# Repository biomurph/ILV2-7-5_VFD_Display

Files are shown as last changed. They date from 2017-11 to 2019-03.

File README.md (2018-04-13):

# ILV2-7-5_VFD_Display
KiCAD circuit for a VFD Clock using the Popular ILV2-7/5 flat tube segmented nixie tube thingie

Not sure if [this link](https://www.ebay.com/itm/Lot-of-20-IVL2-7-5-IVL-VFD-DIGIT-CLOCK-DISPLAY-TUBE-GREEN-Tube-New-FREE-SHIPPING/252890205246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) still works

This work is greatly indebted to work that came before. Namely
[Callum Nunez-Vas](https://callumnunesvaz.wordpress.com/) and his [Dogbone Watch](https://callumnunesvaz.wordpress.com/portfolio/dogbonevfd/) which is also based on the [cyberpunk wristwatch](http://www.johngineer.com/blog/?p=1595) by [johngineer](http://www.johngineer.com/blog/).

I made some changes.

First, my uC is a [PIC32MX250F128B](http://www.microchip.com/wwwproducts/en/PIC32MX250F128B), which supports USB OTG, which is nice and it's also Arduino compatible via ChipKIT and Digilent's [DP32](http://chipkit.net/wiki/index.php?title=ChipKIT_DP32) which makes it nice for sharing.

The other thing that I changed is the oscillator that Callum used to drive the Cathode filament. Callum drives it with a timer on his PIC16F828. I needed more pins, so I decided to make a stand-alone relaxation oscillator built out of a [74HCG214](https://www.mouser.com/ProductDetail/Nexperia/74HC2G14GV125/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) dual Schmidtt Trigger Inverter. I set mine up as a dual oscillator clocking at ~1KHz to drive the hours/mimutes Cathodes. 

There's two pushbuttons for interfacing and an LED for control and user feedback. I'm using the same [DS3231](https://www.maximintegrated.com/en/products/digital/real-time-clocks/DS3231.html) that Callum uses, and also the [MAX6920](https://www.maximintegrated.com/en/products/power/display-power-control/MAX6920.html) for the high voltage SIPO to drive the segments.

It's pretty basic beyond that. The power supply is based on the Dogbone, but I'm using a 3V0 regulator instead of a 3V3 and I have a V-divider set up as a battery level sensor that the PIC can read. 

* Maximum input Voltage 6V
* Minimum input Voltage 3.0V
* Current with VFD DISABLED ~26mA
* Current with VFD ENABLED showing all 8s ~150mA

# Push Button Control

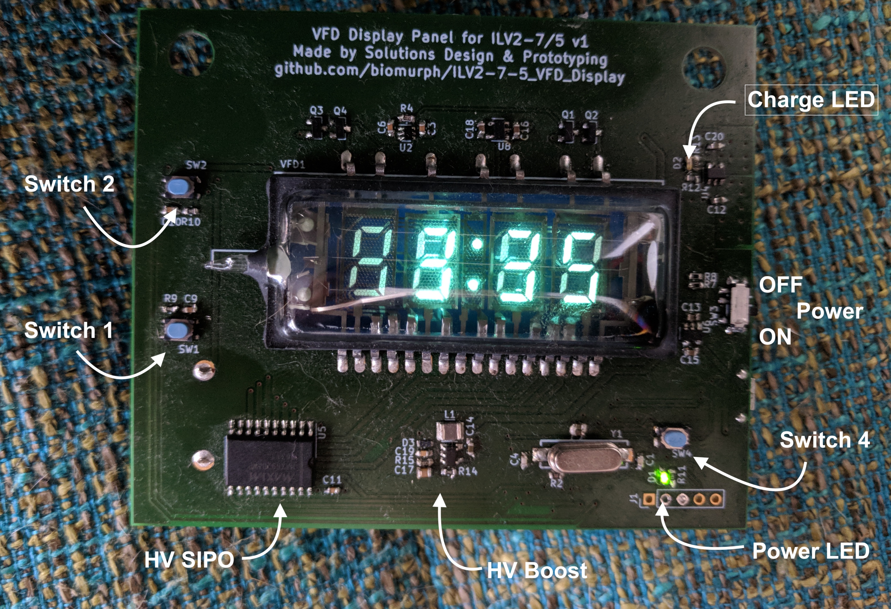
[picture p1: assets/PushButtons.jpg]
PushButtons


## Test Battery Level
Press Switch 2 once. The screen will print a lowercase `b` and then the voltage level with 0.01mV resolution. Press again to go back to time display.

## Change Time
Press Switch 1 once. Hour will blink. Press Switch 2 to increment hour.

Press Switch 1 again. Minute will blink. Press Switch 2 to increment minute.

Press Switch 1 again. Display will show option between 24 hour and 12 hour time. Press Switch 2 to toggle between 24h and 12h.

Press Switch 1 again to go back to the time display.

# Power & Charging

Switch 4 is the reset switch to the PIC. When you press it, the micro-contoller resets. It will start in 24 hour mode.

The thing runs on a high capacity LiPo battery. Plug it into a micro USB cable for charging. You can also program the PIC through the USB connection if you want to.

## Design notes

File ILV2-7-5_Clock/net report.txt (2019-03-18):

Info: Checking netlist symbol footprint “BT1:/5A063A3F:Solutions:12BH062-GR”.

Info: Checking netlist symbol footprint “C1:/5A064980:Capacitors_SMD:C_0603”.

Info: Checking netlist symbol footprint “C2:/5A0722A3:Capacitors_SMD:C_0603”.

Info: Checking netlist symbol footprint “C3:/5A072AB3:Capacitors_SMD:C_0603”.

Info: Checking netlist symbol footprint “C4:/5A0649E6:Capacitors_SMD:C_0603”.

Info: Checking netlist symbol footprint “C5:/5A07216A:Capacitors_SMD:C_0603”.

Info: Checking netlist symbol footprint “C6:/5A0621EE:Capacitors_SMD:C_0603”.

Info: Checking netlist symbol footprint “C7:/5A064D0D:Capacitors_SMD:C_0603”.

Info: Checking netlist symbol footprint “C8:/5A0717BE:Capacitors_SMD:C_0603”.

Info: Checking netlist symbol footprint “C9:/5A073D34:Capacitors_SMD:C_0603”.

Info: Checking netlist symbol footprint “C10:/5A07480A:Capacitors_SMD:C_0603”.

Info: Checking netlist symbol footprint “C11:/5A073321:Capacitors_SMD:C_0603”.

Info: Checking netlist symbol footprint “C13:/5A07925D:Capacitors_SMD:C_0603”.

Info: Checking netlist symbol footprint “Y1:/5A0644EE:Solutions:IQD_HC49_XTAL”.

Info: Checking netlist symbol footprint “C15:/5A0791BA:Capacitors_SMD:C_0603”.

Info: Checking netlist symbol footprint “C16:/5A073399:Capacitors_SMD:C_0603”.

Info: Checking netlist symbol footprint “VFD1:/5A04E81E:Solutions:IVL2-7-5”.

Info: Checking netlist symbol footprint “C17:/5A080FB1:Capacitors_THT:CP_Radial_D5.0mm_P2.00mm”.

Info: Checking netlist symbol footprint “U8:/5A04E091:TO_SOT_Packages_SMD:SOT-23-5”.

Info: Checking netlist symbol footprint “U5:/5A03AB62:Housings_SOIC:SO-20_12.8x7.5mm_Pitch1.27mm”.

Info: Checking netlist symbol footprint “C18:/5A078AB7:Capacitors_SMD:C_0603”.

Info: Checking netlist symbol footprint “C21:/5A09EB84:Capacitors_SMD:C_0603”.

Info: Checking netlist symbol footprint “D1:/5A073B5F:Capacitors_SMD:C_0603”.

Info: Checking netlist symbol footprint “D2:/5AD510A8:Capacitors_SMD:C_0603”.

Info: Changing component path “U4:/5A0386CB” to “/5AD4ED0F”.

Info: Changing component path “D2:/5A07AFE9” to “/5AD510A8”.

Info: Checking netlist symbol footprint “U4:/5AD4ED0F:TO_SOT_Packages_SMD:SOT-23”.

Info: Checking netlist symbol footprint “D3:/5A080969:Capacitors_SMD:C_0603”.

Info: Checking netlist symbol footprint “U3:/5A03A397:SMD_Packages:SOIC-28”.

Info: Checking netlist symbol footprint “J1:/5A076DD7:Pin_Headers:Pin_Header_Straight_1x05_Pitch2.54mm”.

Info: Checking netlist symbol footprint “J2:/5A04E172:Solutions:10118193_microUSB”.

Info: Checking netlist symbol footprint “U2:/5A0513A7:TO_SOT_Packages_SMD:SOT-363_SC-70-6”.

Info: Checking netlist symbol footprint “U1:/5A03A791:SMD_Packages:SOIC-8-N”.

Info: Checking netlist symbol footprint “SW4:/5A08B7A0:Solutions:PTS810”.

Info: Checking netlist symbol footprint “SW3:/5A073A0A:Solutions:C&K_OS102011MS2QN1”.

Info: Checking netlist symbol footprint “SW2:/5A073A78:Solutions:PTS810”.

Info: Checking netlist symbol footprint “SW1:/5A073B03:Solutions:PTS810”.

Info: Checking netlist symbol footprint “R11:/5A073E79:Capacitors_SMD:C_0603”.

Info: Checking netlist symbol footprint “J3:/5AD51382:Connectors:Barrel_Jack_CUI_PJ-102AH”.

Info: Checking netlist symbol footprint “R10:/5A073CB0:Capacitors_SMD:C_0603”.

Info: Checking netlist symbol footprint “Q1:/5A05E086:TO_SOT_Packages_SMD:SOT-23”.

Info: Checking netlist symbol footprint “Q2:/5A0385D3:TO_SOT_Packages_SMD:SOT-23”.

Info: Checking netlist symbol footprint “Q3:/5A062F32:TO_SOT_Packages_SMD:SOT-23”.

Info: Checking netlist symbol footprint “Q4:/5A062F2C:TO_SOT_Packages_SMD:SOT-23”.

Info: Checking netlist symbol footprint “R1:/5A064086:Capacitors_SMD:C_0603”.

Info: Checking netlist symbol footprint “R2:/5A0647AE:Capacitors_SMD:C_0603”.

Info: Checking netlist symbol footprint “R3:/5A06605B:Capacitors_SMD:C_0603”.

Info: Checking netlist symbol footprint “R4:/5A062248:Capacitors_SMD:C_0603”.

Info: Checking netlist symbol footprint “R5:/5A063C78:Capacitors_SMD:C_0603”.

Info: Checking netlist symbol footprint “R6:/5A063CCE:Capacitors_SMD:C_0603”.

Info: Checking netlist symbol footprint “R7:/5C7B733E:Capacitors_SMD:C_0603”.

Info: Checking netlist symbol footprint “R9:/5A073C03:Capacitors_SMD:C_0603”.

Info: Changing component path “R7:/5A08500A” to “/5C7B733E”.

Info: Changing component path “R8:/5A0853B7” to “/5C7B7B7C”.

Info: Checking netlist symbol footprint “R8:/5C7B7B7C:Capacitors_SMD:C_0603”.

Changing footprint “R7:/5A08500A” pad “1” net name from “/BAT_SENS” to “Net-(J2-Pad3)”.

Changing footprint “R8:/5A0853B7” value from “100K” to “22R”.

Changing footprint “R7:/5A08500A” pad “2” net name from “/V_BAT” to “/D+”.

Changing footprint “R8:/5A0853B7” pad “2” net name from “/BAT_SENS” to “/D-”.

Changing footprint “R8:/5A0853B7” pad “1” net name from “GND” to “Net-(J2-Pad2)”.

Changing footprint “R7:/5A08500A” value from “100K” to “22R”.

Adding new symbol “J3:/5AD51382” footprint “Connectors:Barrel_Jack_CUI_PJ-102AH”.

Clearing component “J2:/5A04E172” pin “11” net name.

Clearing component “J2:/5A04E172” pin “8” net name.

Replacing symbol “SW1:/5A073B03” footprint “OpenBCI:PTS810” with “Solutions:PTS810”.

Changing footprint “J2:/5A04E172” pad “3” net name from “/D+” to “Net-(J2-Pad3)”.

Replacing symbol “SW2:/5A073A78” footprint “OpenBCI:PTS810” with “Solutions:PTS810”.

Changing footprint “J2:/5A04E172” pad “2” net name from “/D-” to “Net-(J2-Pad2)”.

Replacing symbol “SW3:/5A073A0A” footprint “Solutions:PCM12SMTR” with “Solutions:C&K_OS102011MS2QN1”.

Changing footprint “SW3:/5A073A0A” pad “2” net name from “/BAT_CHRG” to “+24V”.

Changing footprint “SW3:/5A073A0A” pad “3” net name from “/BAT_CHRG” to “+24V”.

Changing footprint “SW3:/5A073A0A” pad “1” net name from “/V_BAT” to “/V_IN”.

Clearing component “SW3:/5A073A0A” pin “4” net name.

Clearing component “SW3:/5A073A0A” pin “5” net name.

Clearing component “SW3:/5A073A0A” pin “6” net name.

Clearing component “SW3:/5A073A0A” pin “7” net name.

Clearing component “J2:/5A04E172” pin “7” net name.

Replacing symbol “SW4:/5A08B7A0” footprint “OpenBCI:PTS810” with “Solutions:PTS810”.

Clearing component “J2:/5A04E172” pin “9” net name.

Clearing component “J2:/5A04E172” pin “10” net name.

Changing footprint “D3:/5A080969” pad “2” net name from “Net-(D3-Pad2)” to “Net-(C17-Pad1)”.

Changing footprint “U3:/5A03A397” pad “25” net name from “/BAT_SENS” to “Net-(U3-Pad25)”.

Changing footprint “D2:/5A07AFE9” pad “1” net name from “Net-(D2-Pad1)” to “+24V”.

Replacing symbol “U4:/5A0386CB” footprint “TO_SOT_Packages_SMD:SOT-23-5” with “TO_SOT_Packages_SMD:SOT-23”.

Changing footprint “U4:/5A0386CB” value from “MCP73831” to “TLV76033DBZR”.

Changing footprint “D2:/5A07AFE9” value from “LED” to “500mA 30V”.

Changing footprint “U4:/5A0386CB” pad “1” net name from “Net-(R12-Pad1)” to “+3V3”.

Changing footprint “U4:/5A0386CB” pad “2” net name from “GND” to “/V_IN”.

Changing footprint “U4:/5A0386CB” pad “3” net name from “/BAT_CHRG” to “GND”.

Clearing component “U4:/5A0386CB” pin “4” net name.

Clearing component “U4:/5A0386CB” pin “5” net name.

Changing footprint “C17:/5A080FB1” pad “1” net name from “+24V” to “Net-(C17-Pad1)”.

Replacing symbol “C17:/5A080FB1” footprint “Capacitors_SMD:C_0603” with “Capacitors_THT:CP_Radial_D5.0mm_P2.00mm”.

Changing footprint “U8:/5A04E091” value from “MIC5317” to “TC1014-2.5VCT713”.

Changing footprint “U8:/5A04E091” pad “1” net name from “/V_BAT” to “+3V3”.

Changing footprint “C16:/5A073399” pad “1” net name from “/V_BAT” to “+3V3”.

Changing footprint “C13:/5A07925D” pad “1” net name from “/V_BAT” to “/V_IN”.

Removing unused footprint “REF**:”.

Removing unused footprint “B1:/5A0780CF”.

Removing unused footprint “C12:/5A07BEE7”.

Removing unused footprint “C14:/5A073DC5”.

Removing unused footprint “C19:/5A0810B0”.

Removing unused footprint “R12:/5A07B0A9”.

Removing unused footprint “R13:/5A07AEDF”.

Removing unused footprint “R14:/5A0812A5”.

Removing unused footprint “R15:/5A0811E8”.

Removing unused footprint “U6:/5A078602”.

Removing unused footprint “U7:/5A03A4EB”.

Removing unused footprint “C20:/5A08A5CD”.

Removing unused footprint “L1:/5A08028C”.

Removing unused footprint “REF**:”.

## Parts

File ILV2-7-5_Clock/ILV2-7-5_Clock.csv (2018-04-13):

Id | Designator | Package | Quantity | Designation | Supplier and ref
1 | REF**,REF** | MountingHole_6.4mm_M6 | 2 | MountingHole_6.4mm_M6
2 | B1 | JST_RA_SMT | 1 | JS_2_Battery
3 | BT1 | 12BH062-GR | 1 | Battery_Cell
4 | C1,C4 | C_0603 | 2 | 18pF
5 | C2,C13,C15,C16,C18,C21 | C_0603 | 6 | 1uF
6 | C3,C5,C8,C9,C10,C11 | C_0603 | 6 | 0.1uF
7 | C6 | C_0603 | 1 | 0.15uF
8 | C7,C12,C20 | C_0603 | 3 | 10uF
9 | C14 | C_0603 | 1 | 22uF 6.3V
10 | C17 | C_0603 | 1 | 4.7uF 50V
11 | C19 | C_0603 | 1 | 470pF 50V
12 | D1,D2 | C_0603 | 2 | LED
13 | D3 | C_0603 | 1 | 500mA 30V
14 | J2 | 10118193_microUSB | 1 | USB_OTG
15 | Q1,Q3 | SOT-23 | 2 | BSS84
16 | Q2,Q4 | SOT-23 | 2 | BSS138
17 | R1,R4,R5,R6,R9,R10 | C_0603 | 6 | 10k
18 | R2 | C_0603 | 1 | 680R
19 | R3,R14 | C_0603 | 2 | 10K
20 | R7,R8 | C_0603 | 2 | 100K
21 | R11 | C_0603 | 1 | 1k
22 | R12 | C_0603 | 1 | 1K
23 | R13 | C_0603 | 1 | R
24 | R15 | C_0603 | 1 | 150K
25 | SW1,SW2,SW4 | PTS810 | 3 | TACT_SWITCH
26 | U1 | SOIC-8-N | 1 | DS3231M
27 | U2 | SOT-363_SC-70-6 | 1 | 74HC2G14
28 | U3 | SOIC-28 | 1 | PIC32MX250F128B
29 | U4 | SOT-23-5 | 1 | MCP73831
30 | U5 | SO-20_12.8x7.5mm_Pitch1.27mm | 1 | MAX6920
31 | U6,U8 | SOT-23-5 | 2 | MIC5317
32 | U7 | SOT-23-5 | 1 | LMR62421
33 | VFD1 | IVL2-7-5 | 1 | ILV2-7/5
34 | Y1 | IQD_HC49_XTAL | 1 | 8MHz
35 | SW3 | PCM12SMTR | 1 | PCM12SMTR
36 | J1 | Pin_Header_Straight_1x05_Pitch2.54mm | 1 | CONN_01X05
37 | L1 | C_1210 | 1 | 10uH 1.2A

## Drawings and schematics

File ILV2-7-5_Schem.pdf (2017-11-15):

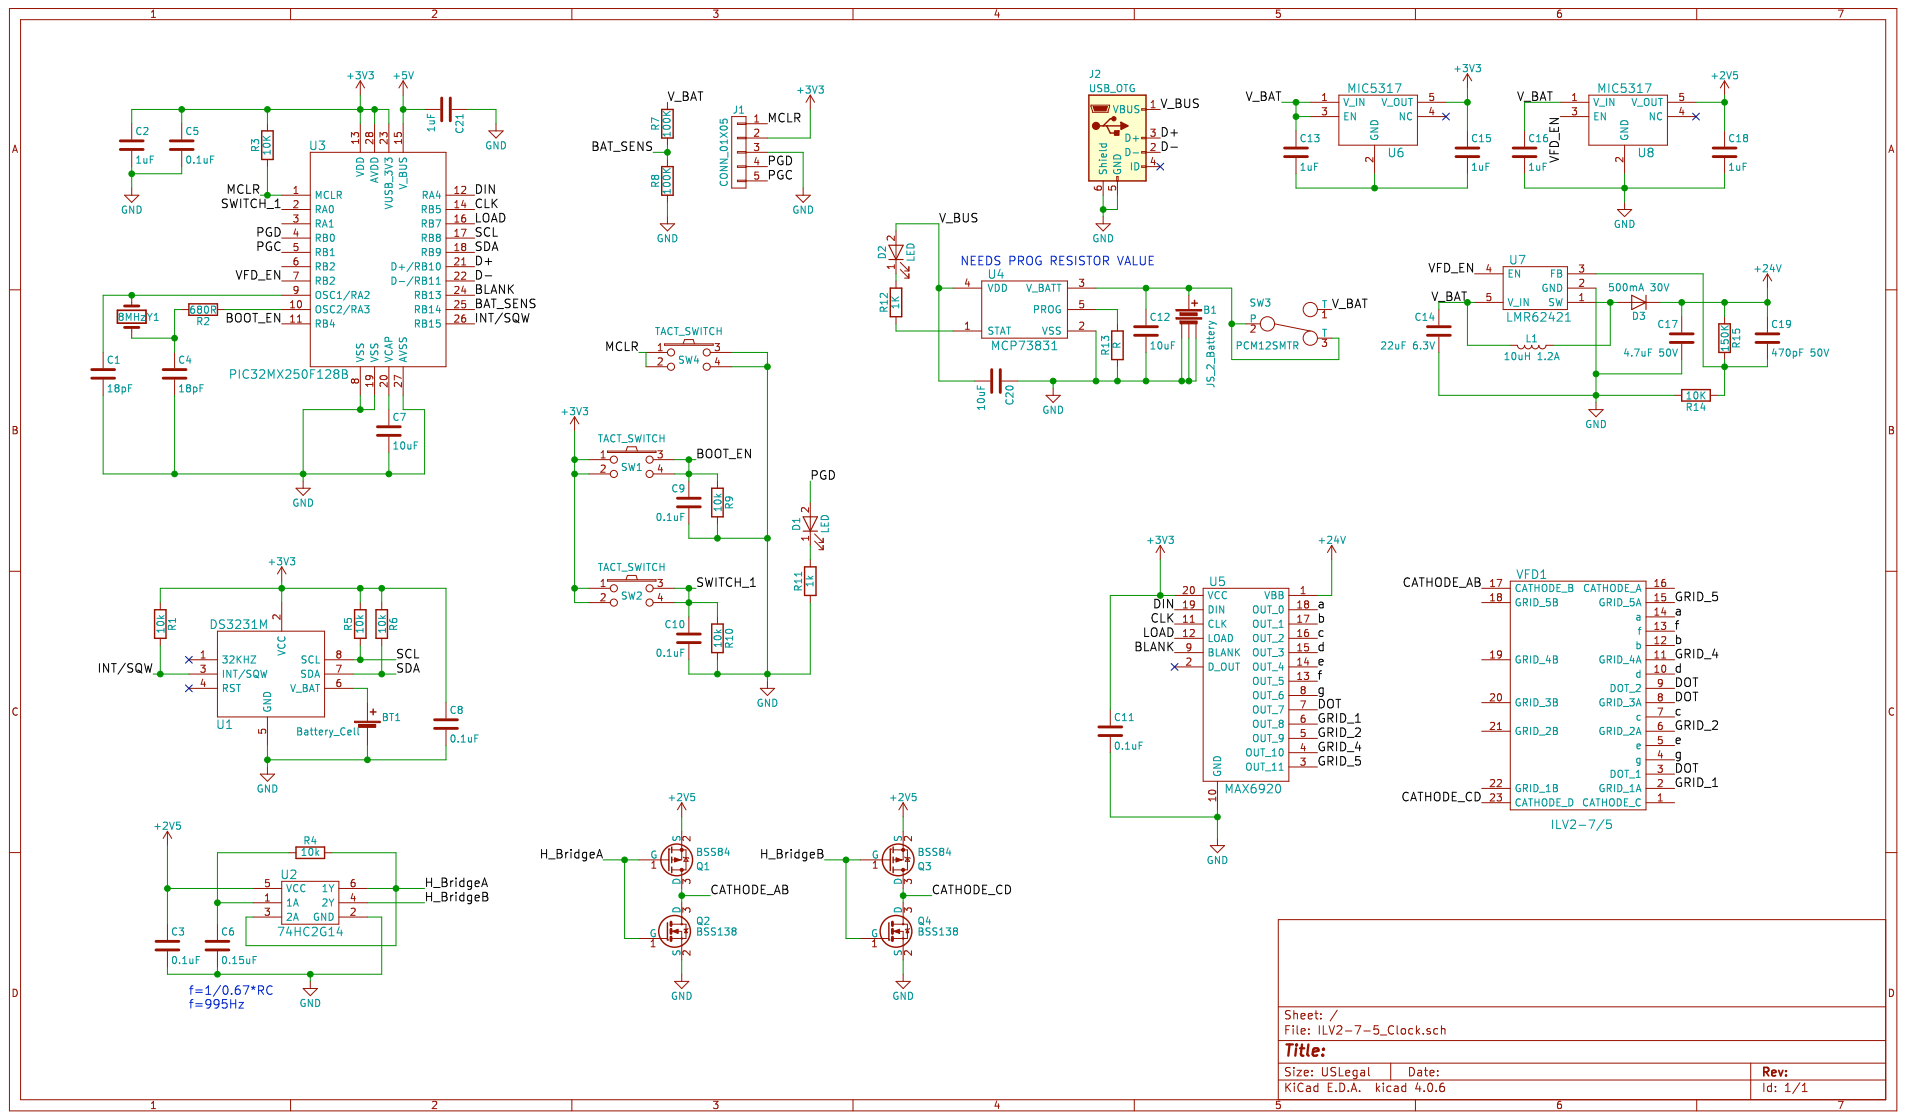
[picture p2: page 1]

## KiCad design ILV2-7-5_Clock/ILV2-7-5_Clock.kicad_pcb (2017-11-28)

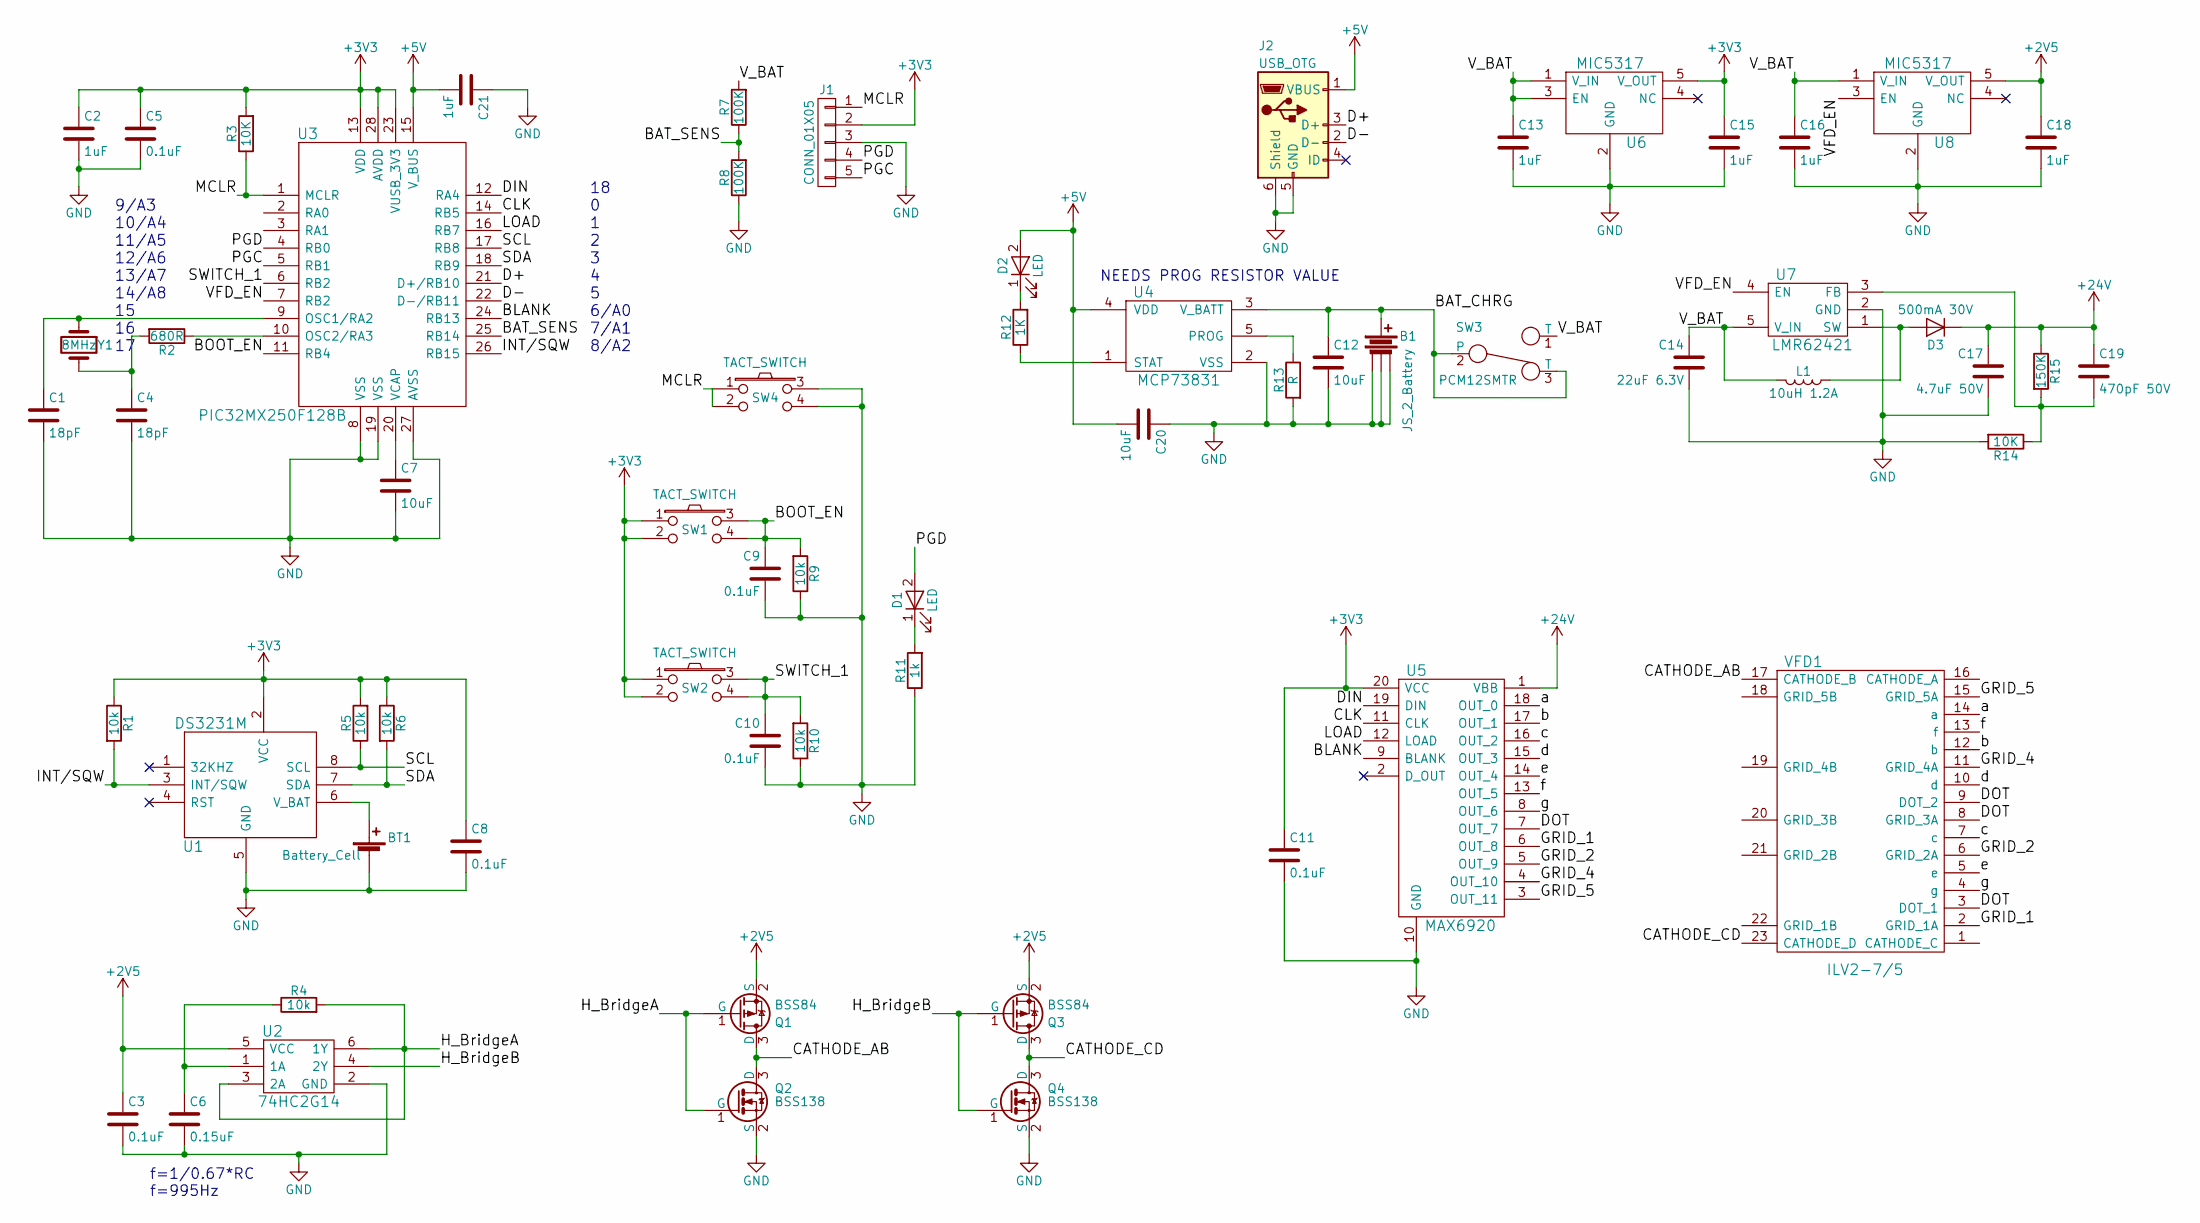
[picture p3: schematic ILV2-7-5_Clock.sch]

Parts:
B1: JS_2_Battery; JST_RA_SMT
BT1: Battery_Cell; 12BH062-GR
C1, C4: 18pF; C_0603
C2, C13, C15, C16, C18, C21: 1uF; C_0603
C3, C5, C8, C9, C10, C11: 0.1uF; C_0603
C6: 0.15uF; C_0603
C7, C12, C20: 10uF; C_0603
C14: 22uF 6.3V; C_0603
C17: 4.7uF 50V; C_0603
C19: 470pF 50V; C_0603
D1, D2: LED; C_0603
D3: 500mA 30V; C_0603
J1: CONN_01X05; Pin_Header_Straight_1x05_Pitch2.54mm
J2: USB_OTG; 10118193_microUSB
L1: 10uH 1.2A; C_1210
Q1, Q3: BSS84; SOT-23
Q2, Q4: BSS138; SOT-23
R1, R4, R5, R6, R9, R10: 10k; C_0603
R2: 680R; C_0603
R3, R14: 10K; C_0603
R7, R8: 100K; C_0603
R11: 1k; C_0603
R12: 1K; C_0603
R13: R; C_0603
R15: 150K; C_0603
SW1, SW2, SW4: TACT_SWITCH; PTS810
SW3: PCM12SMTR
U1: DS3231M; SOIC-8-N
U2: 74HC2G14; SOT-363_SC-70-6
U3: PIC32MX250F128B; SOIC-28
U4: MCP73831; SOT-23-5
U5: MAX6920; SO-20_12.8x7.5mm_Pitch1.27mm
U6, U8: MIC5317; SOT-23-5
U7: LMR62421; SOT-23-5
VFD1: ILV2-7/5; IVL2-7-5
Y1: 8MHz; IQD_HC49_XTAL

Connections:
+2V5: C3.1, C18.1, Q1.2 (S), Q3.2 (S), U2.5 (VCC), U8.5 (V_OUT)
+3V3: C2.1, C5.1, C8.1, C11.1, C15.1, J1.2, R1.1, R3.2, R5.2, R6.1, SW1.1, SW1.2, SW2.1, SW2.2, U1.2 (VCC), U3.13 (VDD), U3.23 (VUSB_3V3), U3.28 (AVDD), U5.20 (VCC), U6.5 (V_OUT)
+5V: C20.2, C21.2, D2.2 (A), J2.1 (VBUS), U3.15 (V_BUS), U4.4 (VDD)
+24V: C17.1, C19.1, D3.1 (K), R15.1, U5.1 (VBB)
/BAT_CHRG: B1.1, C12.1, SW3.2, SW3.3 (T), U4.3 (V_BATT)
/BAT_SENS: R7.1, R8.2, U3.25 (RB14)
/BLANK: U3.24 (RB13), U5.9 (BLANK)
/BOOT_EN: C9.1, R9.2, SW1.3, SW1.4, U3.11 (RB4)
/CATHODE_AB: Q1.3 (D), Q2.3 (D), VFD1.17 (CATHODE_B)
/CATHODE_CD: Q3.3 (D), Q4.3 (D), VFD1.23 (CATHODE_D)
/CLK: U3.14 (RB5), U5.11 (CLK)
/D+: J2.3 (D+), U3.21 (D+/RB10)
/D-: J2.2 (D-), U3.22 (D-/RB11)
/DIN: U3.12 (RA4), U5.19 (DIN)
/DOT: U5.7 (OUT_7), VFD1.3 (DOT_1), VFD1.8 (GRID_3A), VFD1.9 (DOT_2)
/GRID_1: U5.6 (OUT_8), VFD1.2 (GRID_1A)
/GRID_2: U5.5 (OUT_9), VFD1.6 (GRID_2A)
/GRID_4: U5.4 (OUT_10), VFD1.11 (GRID_4A)
/GRID_5: U5.3 (OUT_11), VFD1.15 (GRID_5A)
/H_BridgeA: Q1.1 (G), Q2.1 (G), R4.2, U2.3 (2A), U2.6 (1Y)
/H_BridgeB: Q3.1 (G), Q4.1 (G), U2.4 (2Y)
/INT/SQW: R1.2, U1.3 (INT/SQW), U3.26 (RB15)
/LOAD: U3.16 (RB7), U5.12 (LOAD)
/MCLR: J1.1, R3.1, SW4.1, SW4.2, U3.1 (MCLR)
/PGC: J1.5, U3.5 (RB1)
/PGD: D1.2 (A), J1.4, U3.4 (RB0)
/SCL: R5.1, U1.8 (SCL), U3.17 (RB8)
/SDA: R6.2, U1.7 (SDA), U3.18 (RB9)
/SWITCH_1: C10.1, R10.2, SW2.3, SW2.4, U3.6 (RB2)
/VFD_EN: U3.7 (RB2), U7.4 (EN), U8.3 (EN)
/V_BAT: C13.1, C14.1, C16.1, L1.2, R7.2, SW3.1 (T), U6.1 (V_IN), U6.3 (EN), U7.5 (V_IN), U8.1 (V_IN)
/a: U5.18 (OUT_0), VFD1.14 (a)
/b: U5.17 (OUT_1), VFD1.12 (b)
/c: U5.16 (OUT_2), VFD1.7 (c)
/d: U5.15 (OUT_3), VFD1.10 (d)
/e: U5.14 (OUT_4), VFD1.5 (e)
/f: U5.13 (OUT_5), VFD1.13 (f)
/g: U5.8 (OUT_6), VFD1.4 (g)
GND: B1.2, B1.3, B1.4, BT1.2 (-), C1.2, C2.2, C3.2, C4.2, C5.2, C6.2, C7.2, C8.2, C9.2, C10.2, C11.2, C12.2, C13.2, C14.2, C15.2, C16.2, C17.2, C18.2, C20.1, C21.1, J1.3, J2.5 (GND), J2.6 (Shield), J2.7, J2.8, J2.9, J2.10, J2.11, Q2.2 (S), Q4.2 (S), R8.1, R9.1, R10.1, R11.1, R13.2, R14.2, SW3.4, SW3.5, SW3.6, SW3.7, SW4.3, SW4.4, U1.5 (GND), U2.2 (GND), U3.8 (VSS), U3.19 (VSS), U3.27 (AVSS), U4.2 (VSS), U5.10 (GND), U6.2 (GND), U7.2 (GND), U8.2 (GND)
unnamed: BT1.1 (+), U1.6 (V_BAT)
unnamed: C1.1, U3.9 (OSC1/RA2), Y1.1
unnamed: C4.1, R2.2, Y1.2
unnamed: C6.1, R4.1, U2.1 (1A)
unnamed: C7.1, U3.20 (VCAP)
unnamed: C19.2, R14.1, R15.2, U7.3 (FB)
unnamed: D1.1 (K), R11.2
unnamed: D2.1 (K), R12.2
unnamed: D3.2 (A), L1.1, U7.1 (SW)
unnamed: R2.1, U3.10 (OSC2/RA3)
unnamed: R12.1, U4.1 (STAT)
unnamed: R13.1, U4.5 (PROG)

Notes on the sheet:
f=1/0.67*RC f=995Hz
NEEDS PROG RESISTOR VALUE
18 0 1 2 3 4 5 6/A0 7/A1 8/A2
9/A3 10/A4 11/A5 12/A6 13/A7 14/A8 15 16 17

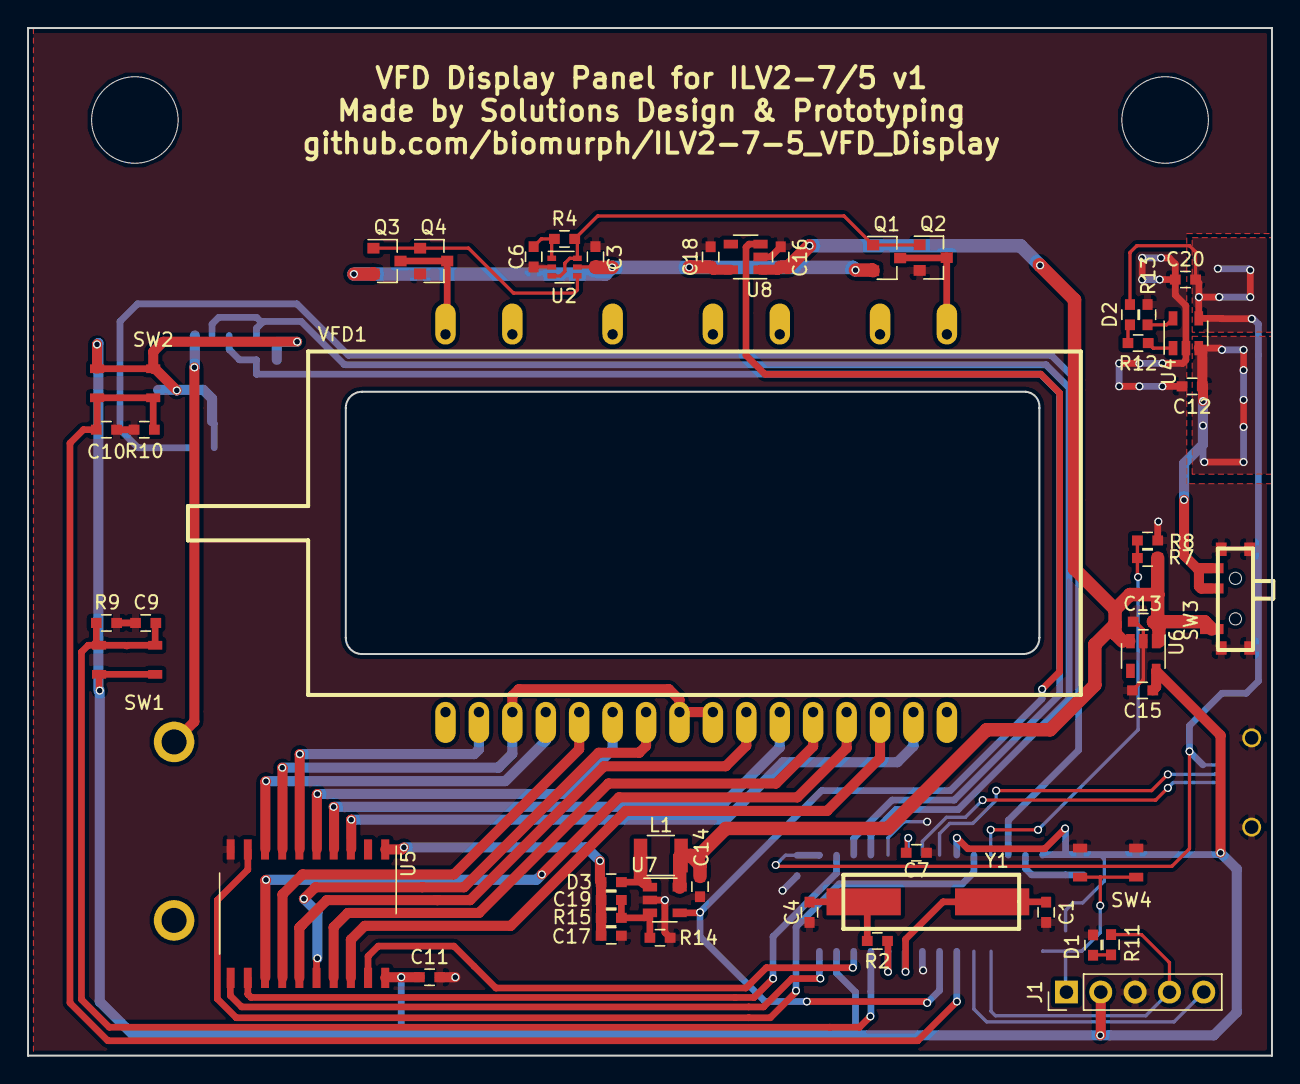
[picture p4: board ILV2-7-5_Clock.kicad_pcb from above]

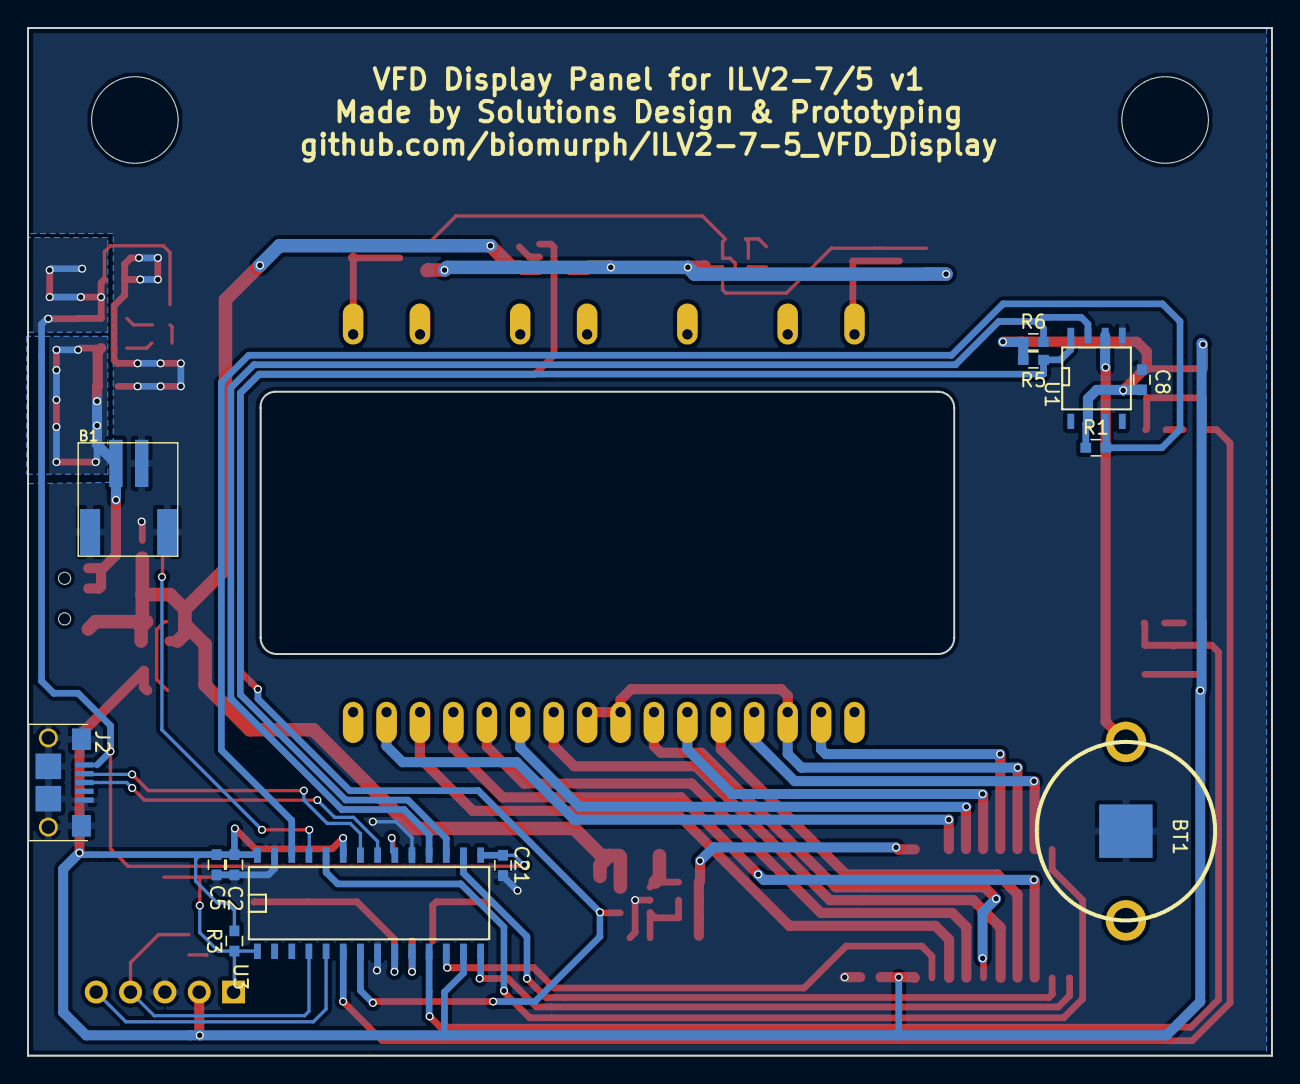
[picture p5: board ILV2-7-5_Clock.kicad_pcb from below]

Board: 2 copper layers, 92.0 x 76.0 mm, 62 parts (13 on the bottom side), 51 nets.

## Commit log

2017-11-12 Completed schematic and first pass of PCB layout
    [ILV2-7-5_Clock.kicad_pcb, ILV2-7-5_Clock.sch, _saved_ILV2-7-5_Clock.sch]
2017-11-12 Small update
    [ILV2-7-5_Clock.sch, _saved_ILV2-7-5_Clock.sch]
2017-11-15 More progress on the PCB and casing down schem issues
    [ILV2-7-5_Clock.kicad_pcb, ILV2-7-5_Clock.sch]
2017-11-20 Finished first draft of pub and zone fills
    [ILV2-7-5_Clock.kicad_pcb, _saved_ILV2-7-5_Clock.sch]
2017-11-20 Added mount holes, fixed the inductor footprint size
    [ILV2-7-5_Clock.kicad_pcb, _saved_ILV2-7-5_Clock.sch]
2017-11-28 Some more such
    [ILV2-7-5_Clock.kicad_pcb, ILV2-7-5_Clock.sch, _saved_ILV2-7-5_Clock.sch]
2017-11-28 Readme updated, etc
    [_saved_ILV2-7-5_Clock.sch]
2017-12-04 Added BOM
    Needs update of some component footprints
    [ILV2-7-5_Clock.csv, ILV2-7-5_Clock.sch, _saved_ILV2-7-5_Clock.sch]
2018-04-13 Updated readme with how to guide
    [_saved_ILV2-7-5_Clock.sch]
2018-04-16 CHANGED FROM BATTERY TO 24V SUPPLY
    [ILV2-7-5_Clock.sch]
2019-03-04 Updated Schematic with parts for desk clock
    [ILV2-7-5_Clock-2019-02-22-12-28-42.sch, ILV2-7-5_Clock-2019-02-22-12-31-31.sch, ILV2-7-5_Clock-2019-02-22-12-32-34.sch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]
2019-03-18 re routed the board. added new footprints
    [ILV2-7-5_Clock.sch]
2020-06-15 Minor Changes
    [ILV2-7-5_Clock.sch]
